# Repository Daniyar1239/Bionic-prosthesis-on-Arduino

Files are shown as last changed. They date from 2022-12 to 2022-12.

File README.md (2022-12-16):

# Bionic-prosthesis-on-Arduino
## A bionic prosthesis controlled through DIY muscle sensors attached to an Arduino board

Instead of using commerical EMG sensors, we've built our own sensors from scratch using electronic components. The raw low-amplitude noisy muscle voltages should be filtered, amplified and rectified to control the servomotors' motion. You can assemble you own circuit using the schematic provided in the repository

For processing the signals and controlling the servomotors, we used the Arduino board and Adafruit Servo Shield. 

The initial hand prosthesis design was taken from https://mdesigns.space/ and has been re-designed for our project. 



Please, watch the video demonstrations and the presentation to grasp the project details. 

Contact me if you willing to reproduce this experiment by writing to daniyar.zhakyp@nu.edu.kz

Good luck!

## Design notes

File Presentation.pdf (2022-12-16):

# ArmOrQol

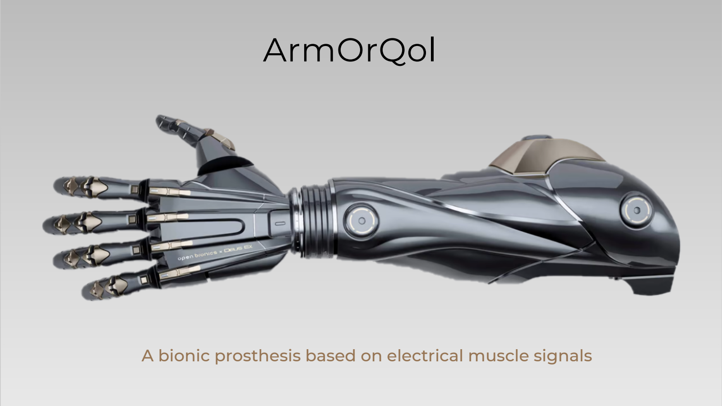
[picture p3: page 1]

A bionic prosthesis based on electrical muscle signals

## Aim of the project

In Kazakhsta, there are
12794

people with upper and lower limb amputatations

Approximately
5000

prostheses are purchased by the government annualy

Most of them are mechanical, where one's price exceeds

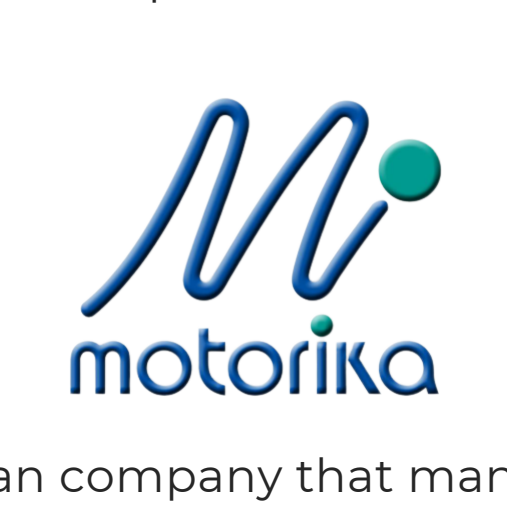
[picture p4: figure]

A Russian company that manufactures | 700,000 KZT

bionic prostheses

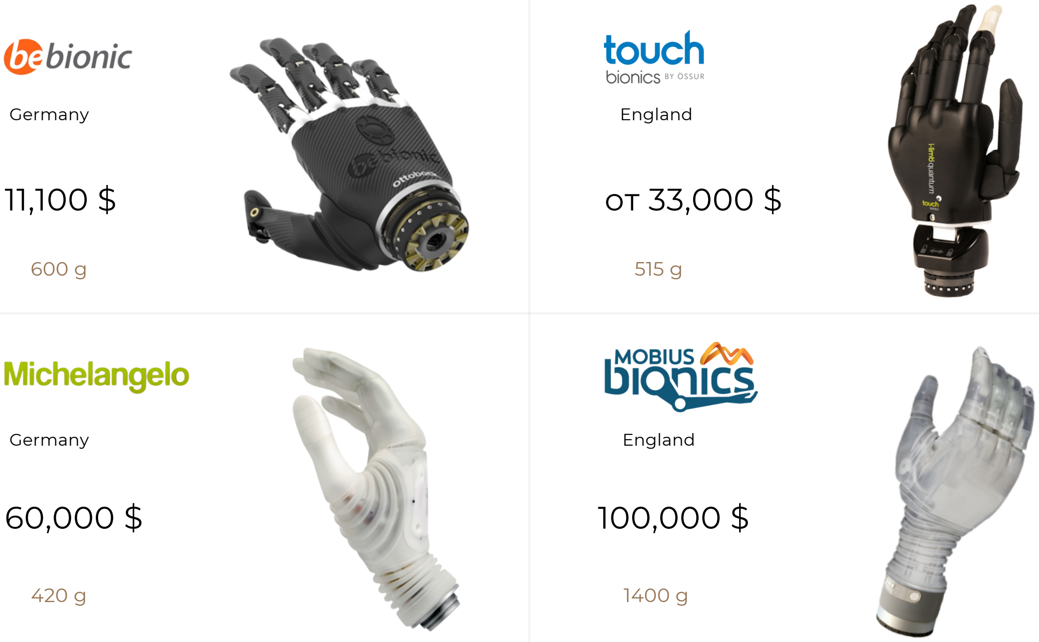
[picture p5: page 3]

11,100 $

600 g

Germany | England

от 33,000 $

515 g

Germany

60,000 $

420 g

England

100,000 $

1400 g

Вy

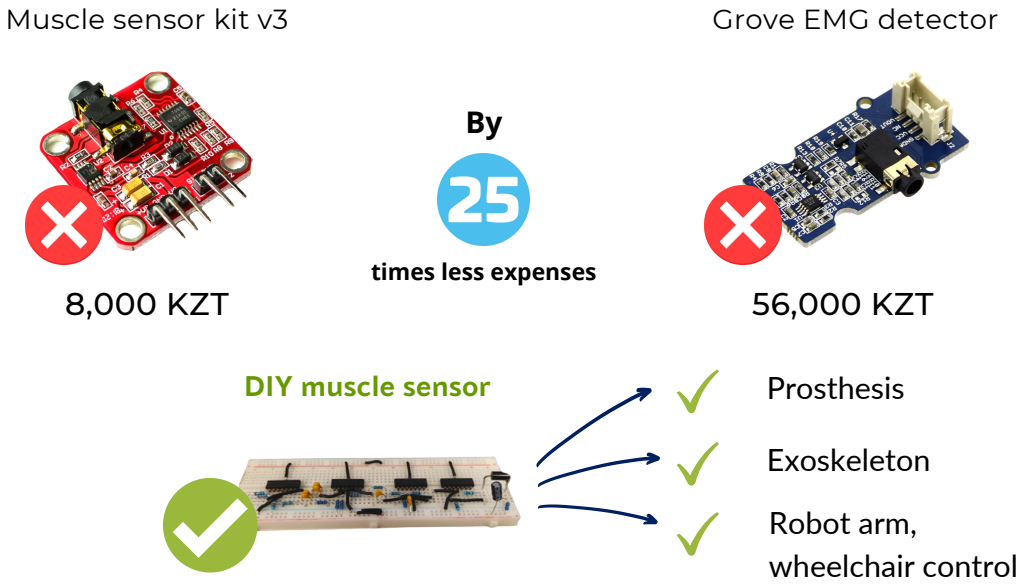
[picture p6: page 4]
8,000 KZT; 56,000 KZT; Muscle sensor kit v3; Grove EMG detector; DIY muscle sensor; Prosthesis; Exoskeleton; Robot arm, wheelchair control

times less expenses

# Principle of work

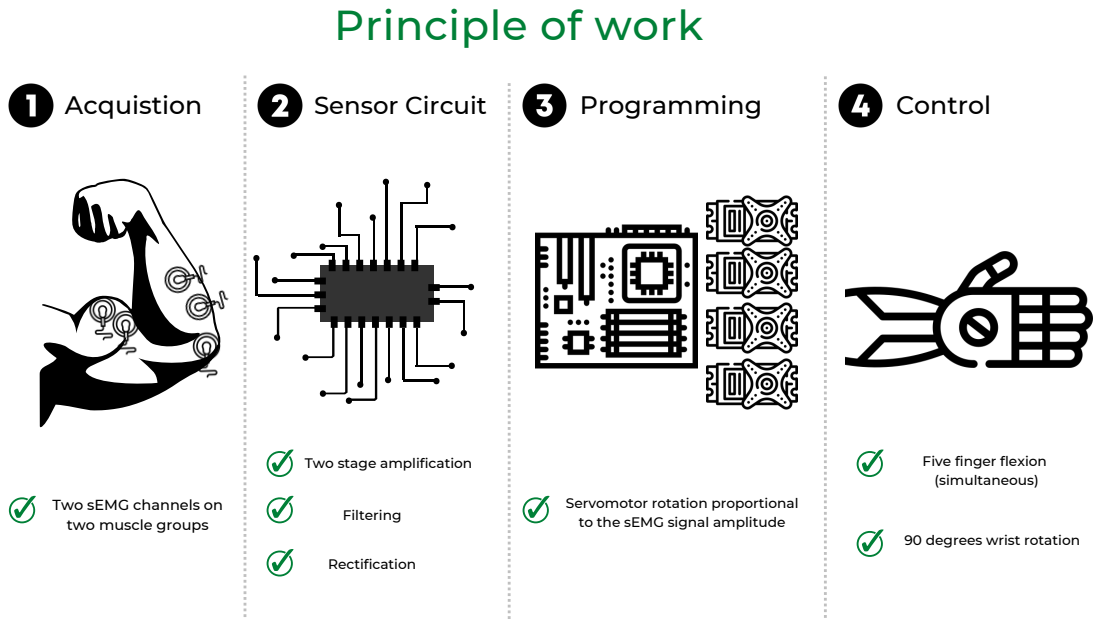
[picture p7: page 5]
Acquistion; Sensor Circuit; Programming; Filtering; Rectification; Control

Two stage amplification

Five finger flexion
(simultaneous)

Two sEMG channels on
two muscle groups

Servomotor rotation proportional
to the sEMG signal amplitude

90 degrees wrist rotation

# Сost price: 47,459KZT

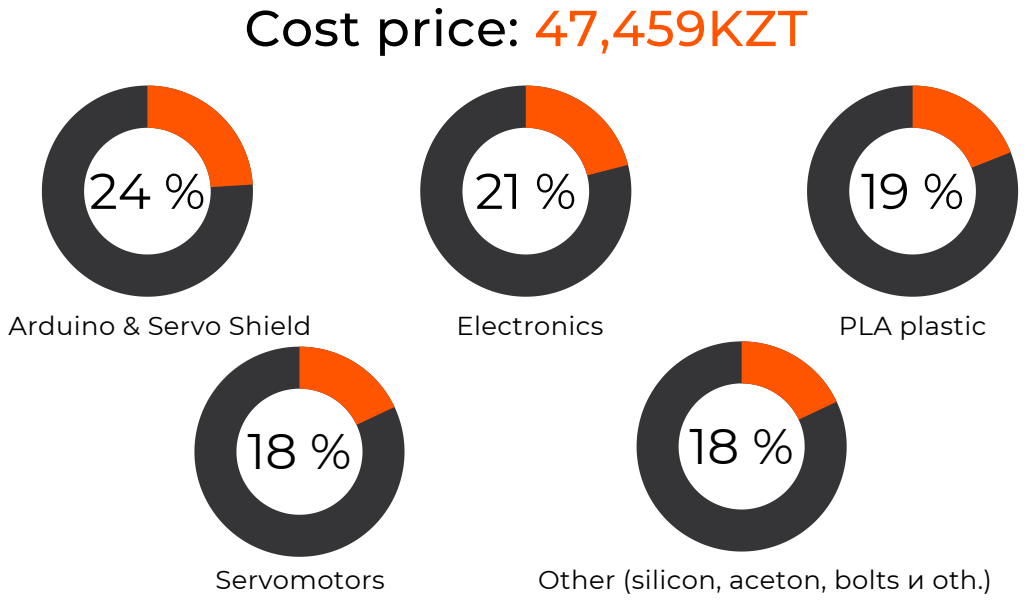
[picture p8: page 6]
Arduino & Servo Shield; Electronics; PLA plastic; Servomotors; Other (silicon, aceton, bolts и oth.)

## 3D model of the prosthesis

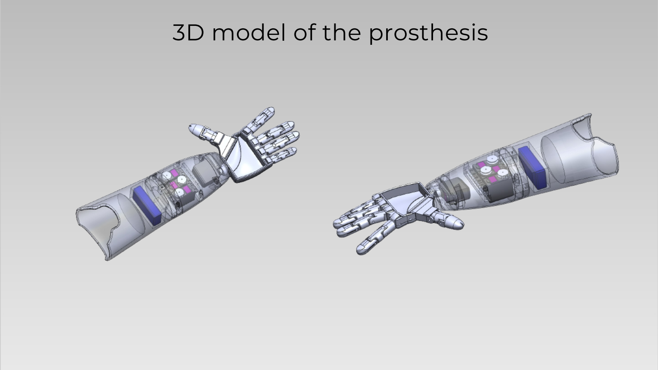
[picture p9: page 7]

## Project demonstration

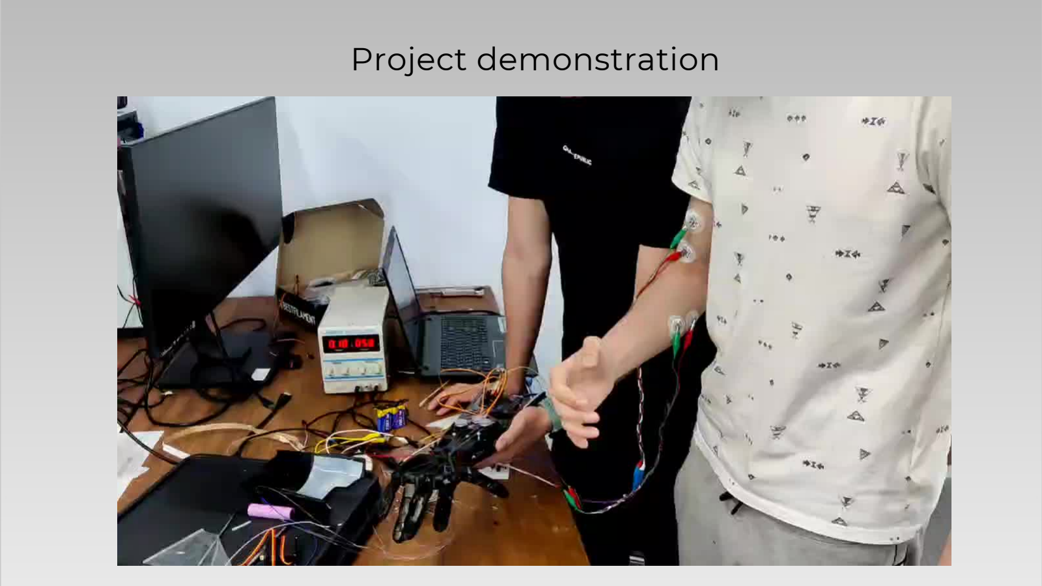
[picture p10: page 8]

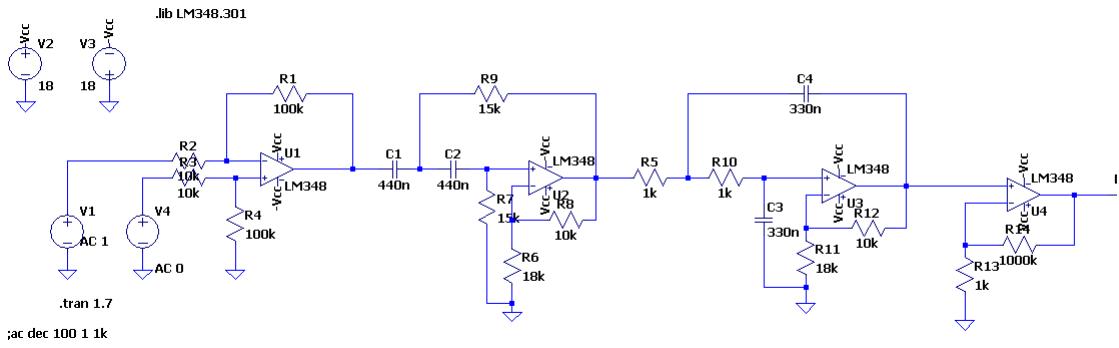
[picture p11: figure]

Figure 1. The EMG sensor circuit in LTSpice XVII

## Appendix

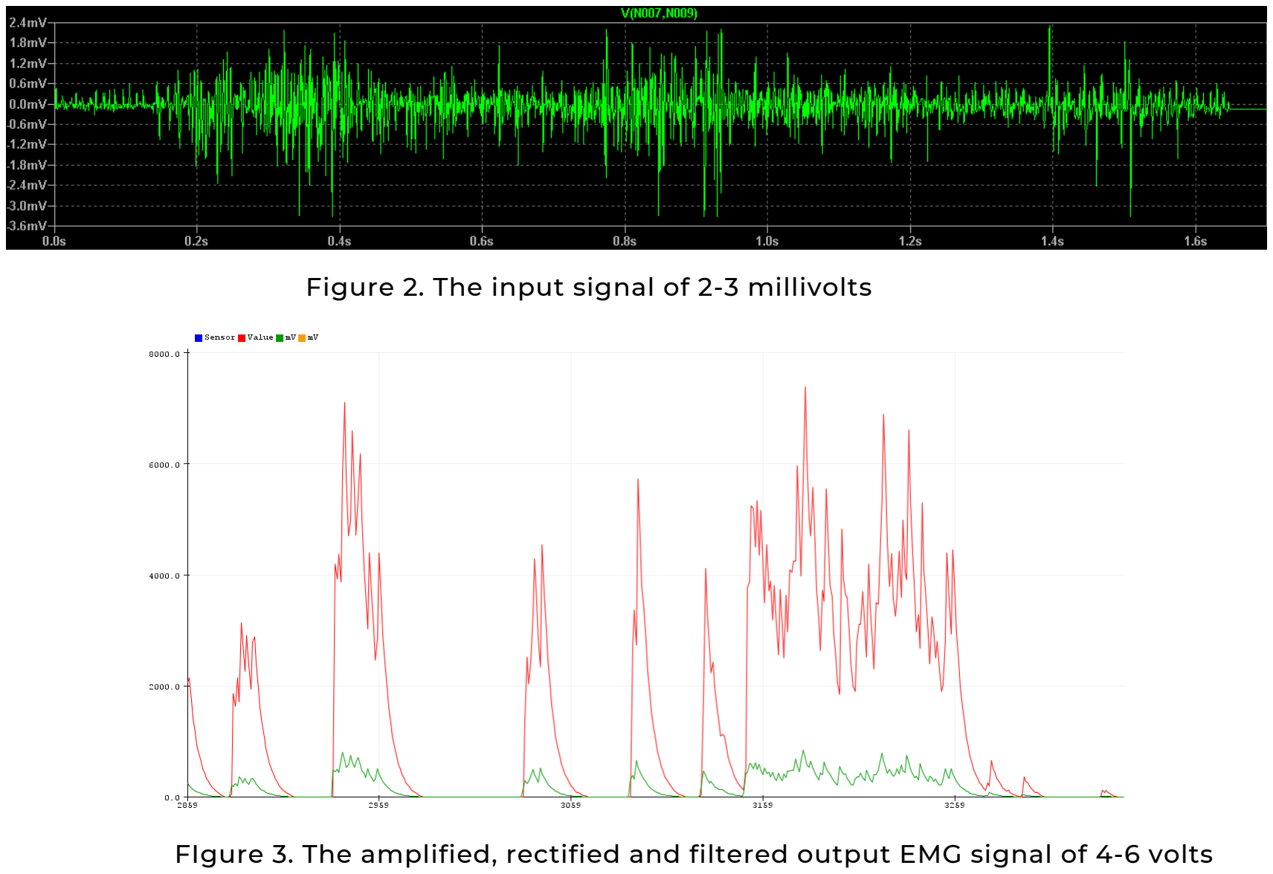
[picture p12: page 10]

Figure 2. The input signal of 2-3 millivolts

FIgure 3. The amplified, rectified and filtered output EMG signal of 4-6 volts

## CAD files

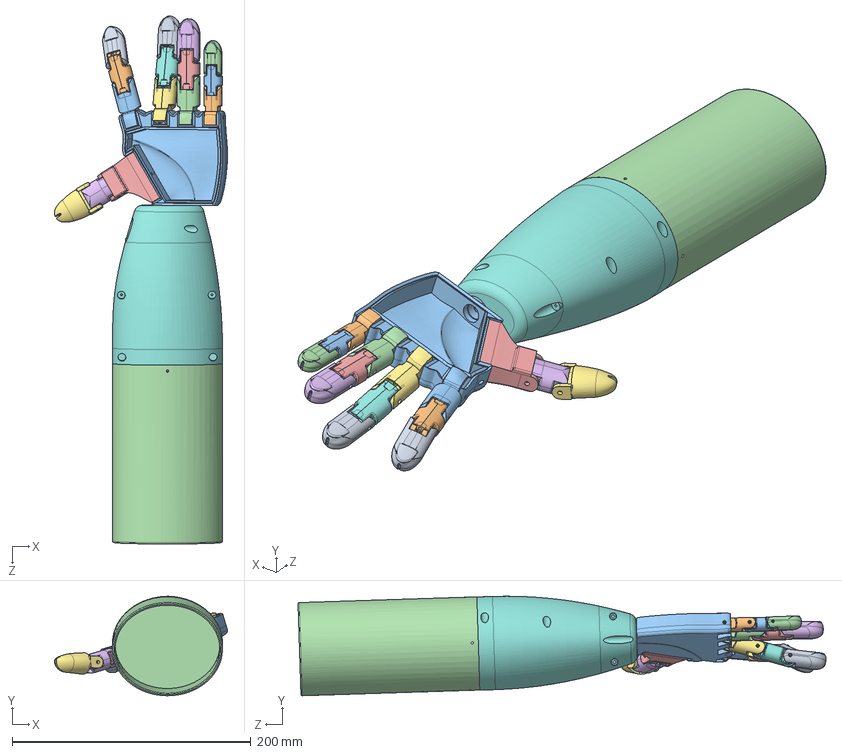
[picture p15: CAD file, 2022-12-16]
Prosthetic Arm 3D files/Full Assembly Exploded.SLDASM
145.1 x 83.4 x 442.5 mm
Index Finger Tip
Index Finger Middle
Index Finger Bottom Plus Cutout
Ring Finger Bottom Plus Cutout
Ring Finger Middle
Ring Finger Tip
Middle Finger Bottom Plus Cutout
Middle Finger Middle
Middle Finger Tip
Pinky Finger Bottom Plus Cutout
Pinky Finger Middle
Pinky Finger Tip
Thumb Lower
Thumb Middle
Thumb tip 2
Forearm
Standard Servo x 4
Horn x 3
Palm _ Optimised Connector

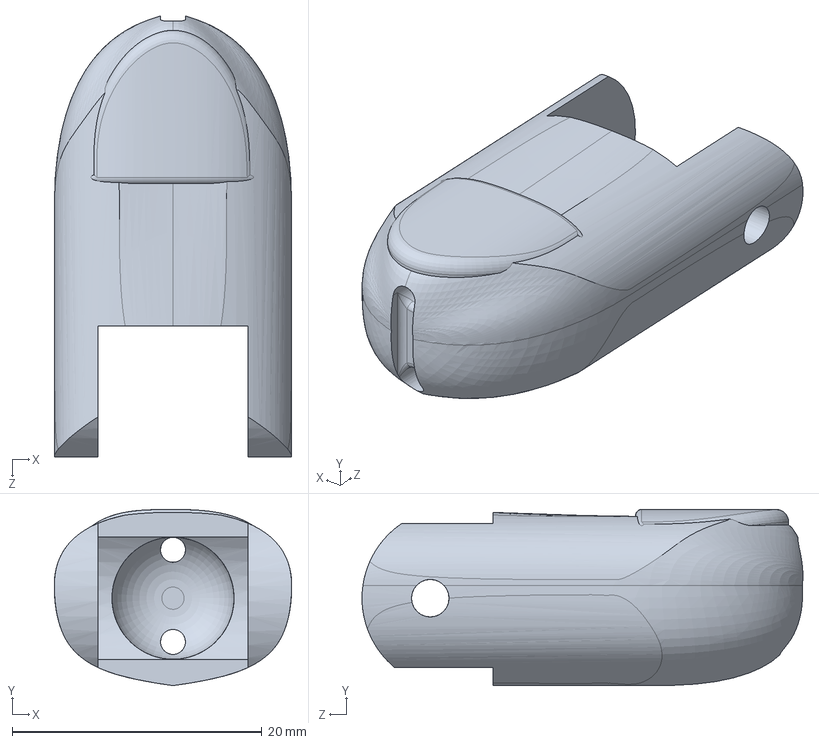
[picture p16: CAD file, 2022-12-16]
Prosthetic Arm 3D files/Middle Finger Tip.SLDPRT
19.0 x 14.1 x 35.3 mm

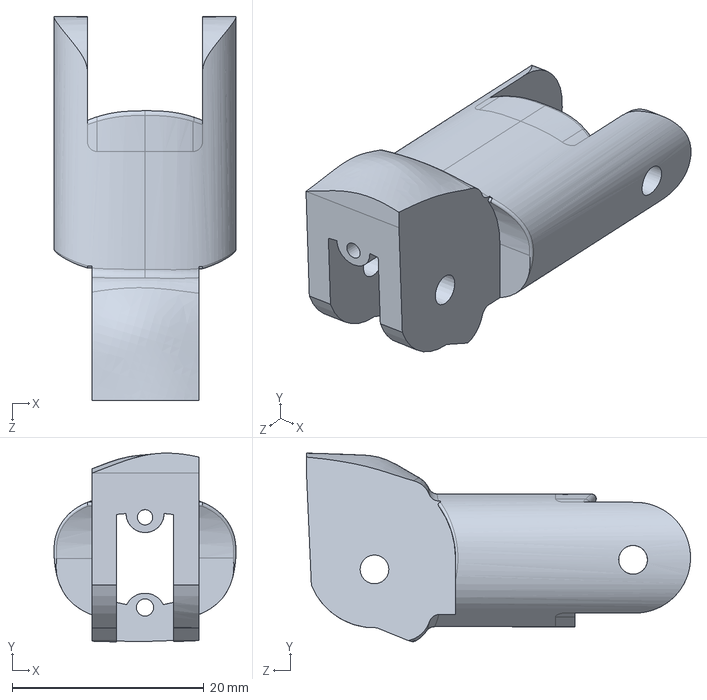
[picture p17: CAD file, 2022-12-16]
Prosthetic Arm 3D files/Index Finger Bottom Plus Cutout.SLDPRT
19.0 x 19.7 x 40.1 mm

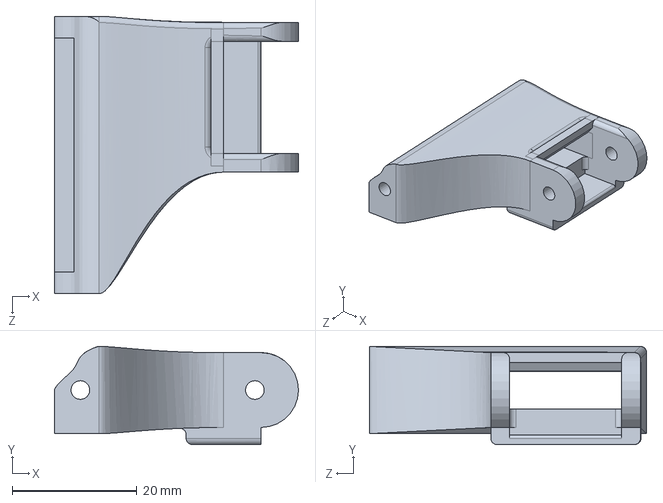
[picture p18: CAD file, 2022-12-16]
Prosthetic Arm 3D files/Thumb Lower.SLDPRT
39.1 x 15.8 x 44.5 mm

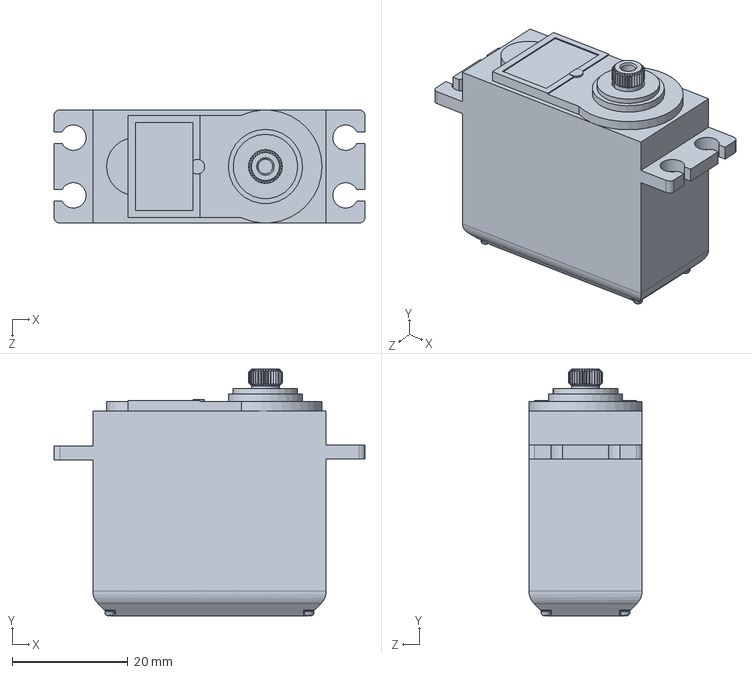
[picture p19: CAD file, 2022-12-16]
Prosthetic Arm 3D files/Standard Servo.SLDPRT
53.7 x 42.6 x 19.6 mm

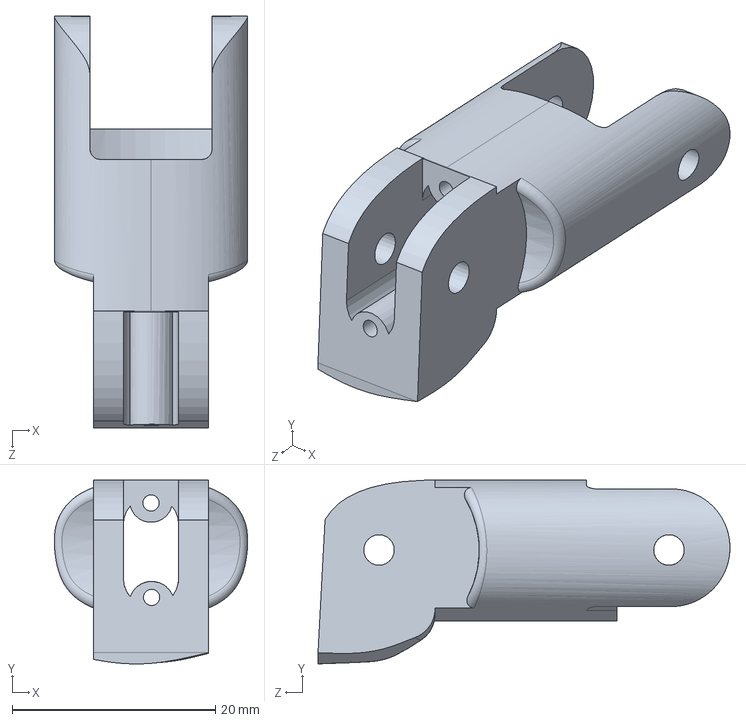
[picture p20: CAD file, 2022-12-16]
Prosthetic Arm 3D files/Middle Finger Bottom Plus Cutout.SLDPRT
19.0 x 18.1 x 40.5 mm

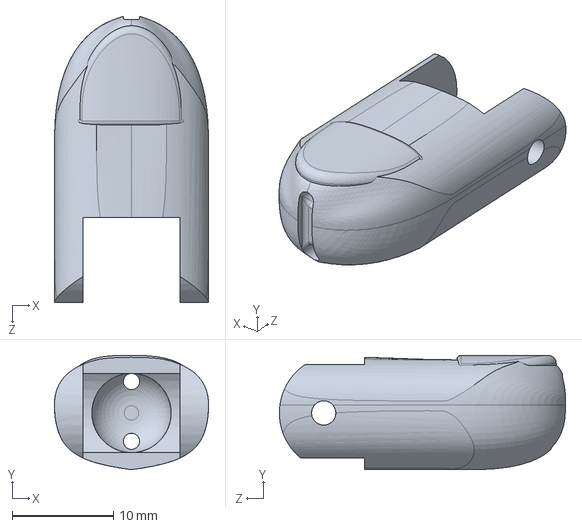
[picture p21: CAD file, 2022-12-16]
Prosthetic Arm 3D files/Pinky Finger Tip.SLDPRT
15.2 x 11.3 x 28.3 mm

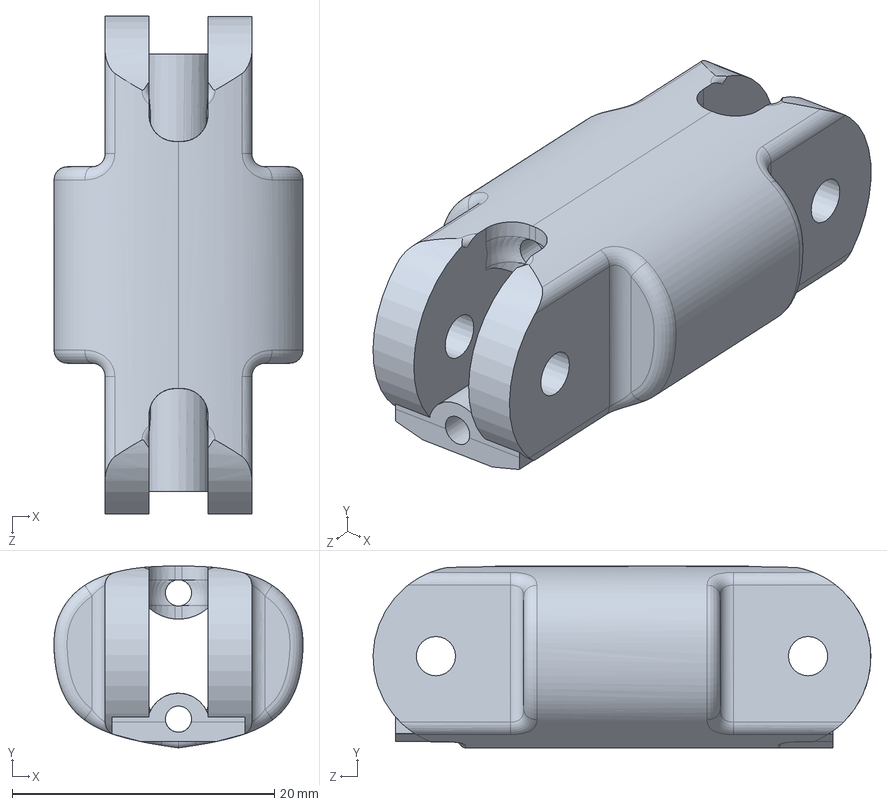
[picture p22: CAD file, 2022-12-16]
Prosthetic Arm 3D files/Middle Finger Middle.SLDPRT
19.0 x 13.9 x 38.0 mm

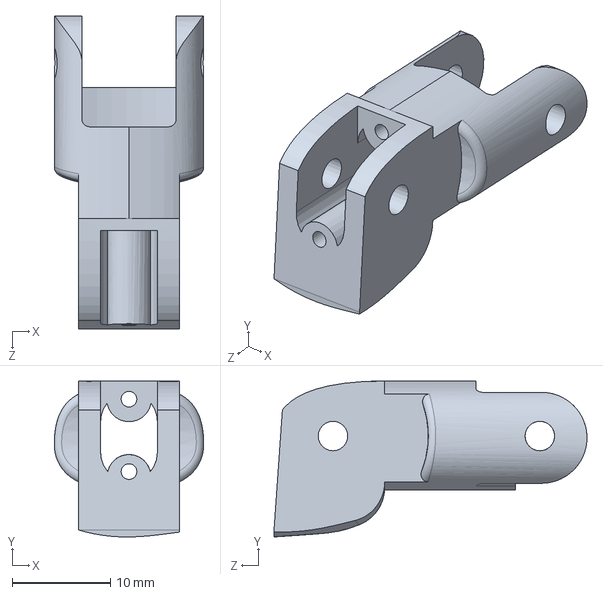
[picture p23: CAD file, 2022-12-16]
Prosthetic Arm 3D files/Pinky Finger Bottom Plus Cutout.SLDPRT
15.2 x 15.9 x 31.9 mm

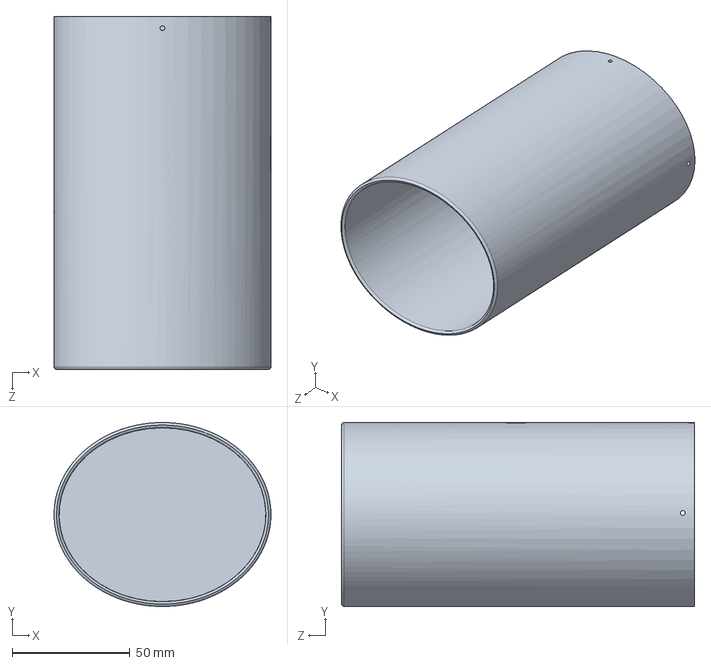
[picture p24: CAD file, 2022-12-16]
Prosthetic Arm 3D files/part 1.SLDPRT
92.2 x 78.2 x 150.0 mm

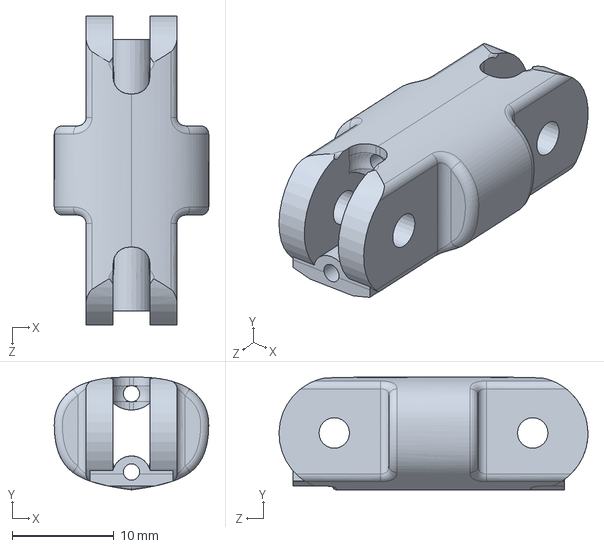
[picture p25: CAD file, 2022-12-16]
Prosthetic Arm 3D files/Pinky Finger Middle.SLDPRT
15.2 x 11.1 x 30.4 mm

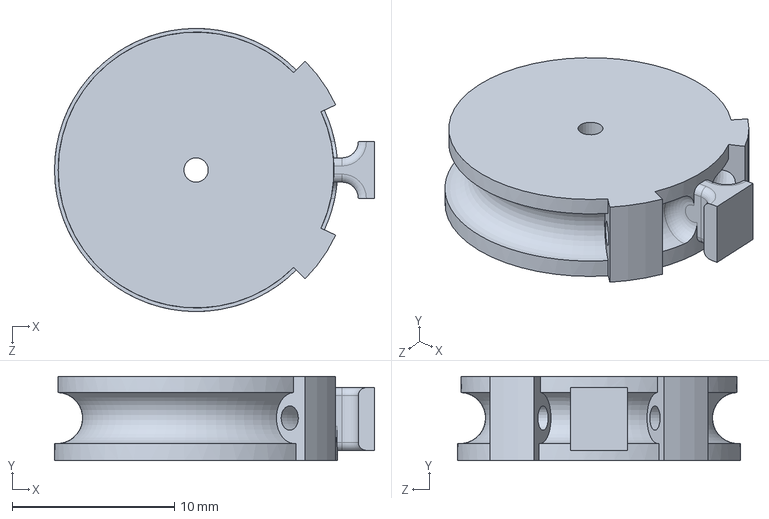
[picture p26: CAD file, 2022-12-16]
Prosthetic Arm 3D files/Horn.SLDPRT
19.7 x 5.20 x 17.5 mm

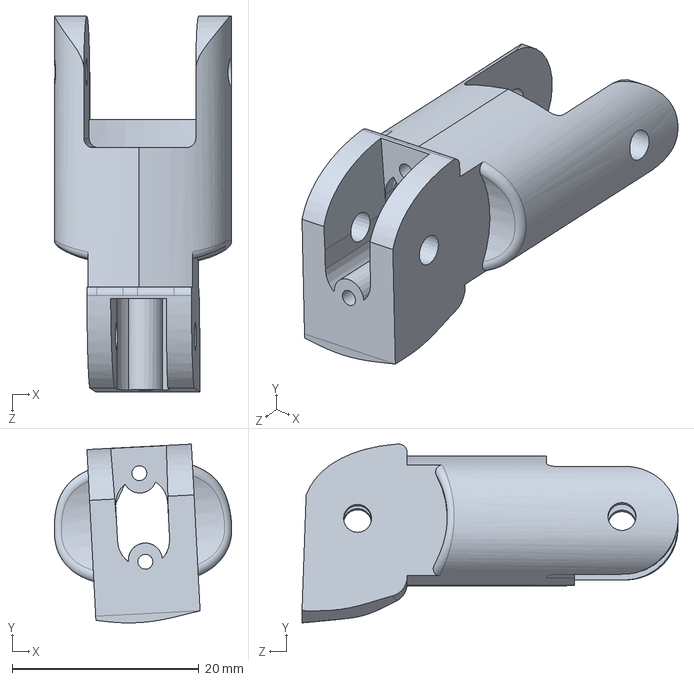
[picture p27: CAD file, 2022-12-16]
Prosthetic Arm 3D files/Ring Finger Bottom Plus Cutout.SLDPRT
19.0 x 19.2 x 40.3 mm

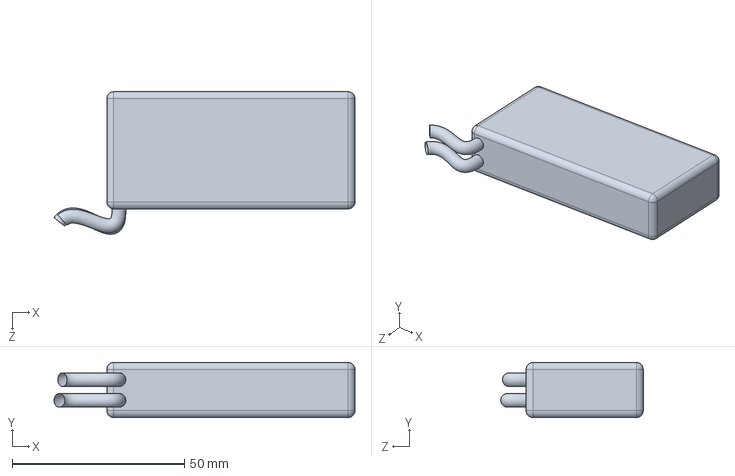
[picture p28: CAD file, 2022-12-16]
Prosthetic Arm 3D files/Battery.SLDPRT
87.3 x 16.0 x 41.4 mm

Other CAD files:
Prosthetic Arm 3D files/Index Finger Tip.SLDPRT
Prosthetic Arm 3D files/Index Finger Middle.SLDPRT
Prosthetic Arm 3D files/Ring Finger Tip.SLDPRT
Prosthetic Arm 3D files/Ring Finger Middle.SLDPRT
Prosthetic Arm 3D files/Forearm.SLDPRT
Prosthetic Arm 3D files/Palm _ Optimised Connector.SLDPRT
Prosthetic Arm 3D files/Thumb Middle.SLDPRT
Prosthetic Arm 3D files/Thumb tip 2.SLDPRT
Prosthetic Arm 3D files/spur gear_iso.sldprt

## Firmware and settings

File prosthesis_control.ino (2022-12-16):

#include <Wire.h>

#include <Adafruit_PWMServoDriver.h>

#define MIN_PULSE_WIDTH       650
#define MID_PULSE_WIDTH       1500
#define MAX_PULSE_WIDTH       2350
#define FREQUENCY             50
 
Adafruit_PWMServoDriver pwm = Adafruit_PWMServoDriver();

int sensor1 = A0;
int sensor2 = A1; 

int motorRL = 0;   //Ring+Little
int motorMI = 4;   //Middle+Index
int motorT = 8;    //Thumb
int motorW = 12;    //Wrist

void setup() {
  pwm.begin();
  pwm.setPWMFreq(FREQUENCY);
  Serial.begin(9600);

}

void moveMotorFist(int controlIn, int motorOut)
{
  int pulse_wide, pulse_width, emgVal;
  
  // Read values from emg sensor
  emgVal = analogRead(controlIn);
  
  // Convert to pulse width
  pulse_wide = map(emgVal, 0, 1023, MIN_PULSE_WIDTH, MAX_PULSE_WIDTH);
  pulse_width = int(float(pulse_wide) / 1000000 * FREQUENCY * 4096);
  
  Serial.println(pulse_width);
  
  //Control Motor
  if(pulse_width>200){
    pwm.setPWM(motorOut, 0, 480);  
    }

  else if(pulse_width<100){
    pwm.setPWM(motorOut, 0, 0);
    }
  else{
      pwm.setPWM(motorOut, 0, pulse_width);
    }
  
 
}

void moveMotorWrist(int controlIn, int motorOut)
{
  int pulse_wide, pulse_width, emgVal;
  
  // Read values from emg sensor
  emgVal = analogRead(controlIn);
  
  // Convert to pulse width
  pulse_wide = map(emgVal, 0, 1023, MID_PULSE_WIDTH, MAX_PULSE_WIDTH);
  pulse_width = int(float(pulse_wide) / 1000000 * FREQUENCY * 4096);
  Serial.println(pulse_width);
  
  if(pulse_width>350){
    pwm.setPWM(motorOut, 0, 480);  
    }

  else if(pulse_width<100){
    pwm.setPWM(motorOut, 0, 0);
    }
  else{
      pwm.setPWM(motorOut, 0, pulse_width);
    }
    
}

void loop() {
   moveMotorFist(sensor1, motorRL);

   moveMotorFist(sensor1, motorMI);


   moveMotorFist(sensor1, motorT);

   moveMotorWrist(sensor2, motorW);
   



}
